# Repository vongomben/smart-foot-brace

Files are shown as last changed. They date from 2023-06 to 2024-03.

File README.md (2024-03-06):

A project managed by [Officine Innesto](https://officine.cc/smart-foot-brace-a-project-with-its-biotecnologie-from-colleretto-giacosa/) in collaboration with students from [ITS Biotecnologie](https://www.its-biotecnologiepiemonte.it/) from Colleretto Giacosa / Torino, Italy. 

# smart-foot-brace
notes over a smart foot brace based on ZNX-01 and IMU, communicating with a Node-RED UI (vers 01. and 0.2) and later using [BLE and P5js](https://github.com/vongomben/smart-foot-brace/tree/main/ble) (vers 0.3)

## Version 0.3 Bluetooth Low Energy Version

Video Demo (https://www.youtube.com/watch?v=2Io1VRFC9aA)

The sole sends data via BLE. 
To visualize this project we used p5js, and its implementation of the BLE library
Here is [the code](https://editor.p5js.org/vongomben/sketches/Wb9gCTJpH)

La suola trasmette tutti i dati attraverso bluetooth. 
Per visualizzare questo progetto abbiamo usato p5js, e la sua implementazione della libreria BLE
Qui il [codice](https://editor.p5js.org/vongomben/sketches/Wb9gCTJpH)

## Version 0.2 ESP32 + ZNX + IMU! + UI in Node-RED

Video Demo (https://www.youtube.com/watch?v=2a6iHeYnoPc)
(sorry this is note yet subtitled)

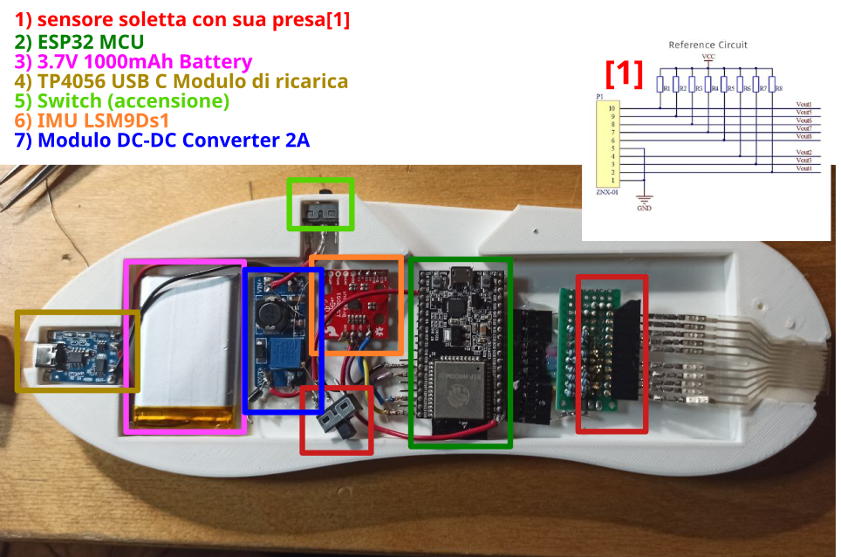
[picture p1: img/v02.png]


|ref|description |label  |Manufacturer|MPN |DPN |link |
|---|---|---|---|---|---|---|
|1  |Sensore Soletta |ZNX-01 |Qiter |Qiter4hr835o19f |B08CXZ6QWM |https://www.amazon.it/intelligente-pressione-Accessorio-tappetino-sensibile/dp/B08CXZ6QWM |
|2  |MCU |ESP32  |AZDelivery  |B071P98VTG |B071P98VTG |https://www.amazon.it/AZDelivery-NodeMCU-Development-Arduino-gratuito/dp/B071P98VTG/ |
|3  | 3.7V 1000mAh Battery |Battery|AKZYTUE |A202106326 |A202106326 |https://www.amazon.it/AKZYTUE-Batteria-ricaricabile-polimeri-connettore/dp/B0983K9BMK/ |
|4  |TP4056 USB C Tipo C Modulo di ricarica (3)|Charger|RED DAMORE  |B0BJQPN3RG |B0BJQPN3RG |https://www.amazon.it/RED-DAMORE-ricarica-batteria-protezione/dp/B0BJQPN3RG/ |
|~5~  |~DC-DC Buck Converter (6)~ |Buck |DUBEUYEW |B0B4SYBGQL |B0B4SYBGQL |https://www.amazon.it/DUBEUYEW-Converter-Modulo-alimentazione-regolabile/dp/B0B4SYBGQL |
|6  |Interruttore a Scorrimento |SWITCH |RUNCCI-YUN  |B09TVDZ8P2 |B09TVDZ8P2 |https://www.amazon.it/RUNCCI-YUN-Interruttore-Scorrimento-Posizione-Elettronici/dp/B09TVDZ8P2/|
|7  |FILAMENT |3D |SUNLU |‎SLUK-TPU-WT-0.5KG|‎SLUK-TPU-WT-0.5KG|https://www.amazon.it/SUNLU-Filament-Dimensional-Accuracy-Printing/dp/B07R6PMXSP |
|8  |IMU LSM9Ds1 |IMU |Sparkfun |SEN-13284 |SEN-13284 |https://www.sparkfun.com/products/retired/13284 |
|9  |MODULO DC-DC BOOST CONVERTER 2 AMPERE |Buck |Pinto |056.044.3838 |056.044.3838 | |

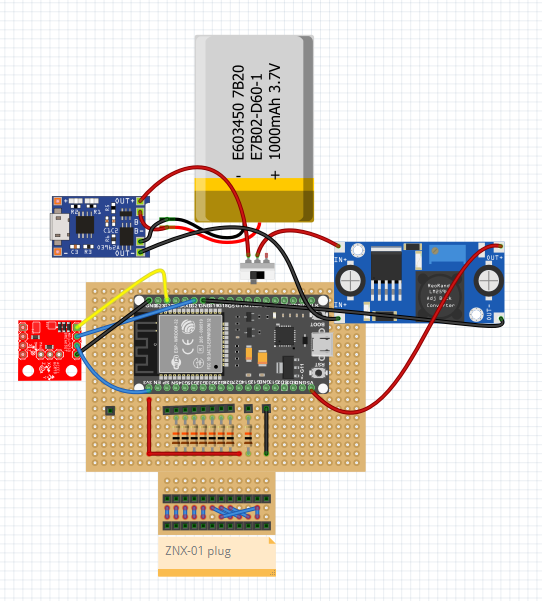
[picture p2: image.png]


Old info about version #1 (Italian only)

## Version 0.1 ESP32 + ZNX + UI in Node-RED

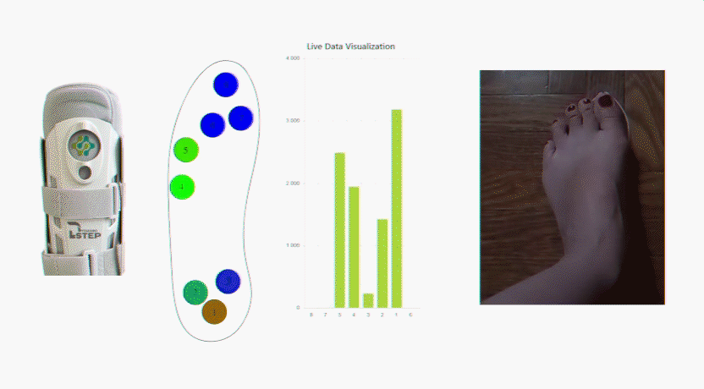
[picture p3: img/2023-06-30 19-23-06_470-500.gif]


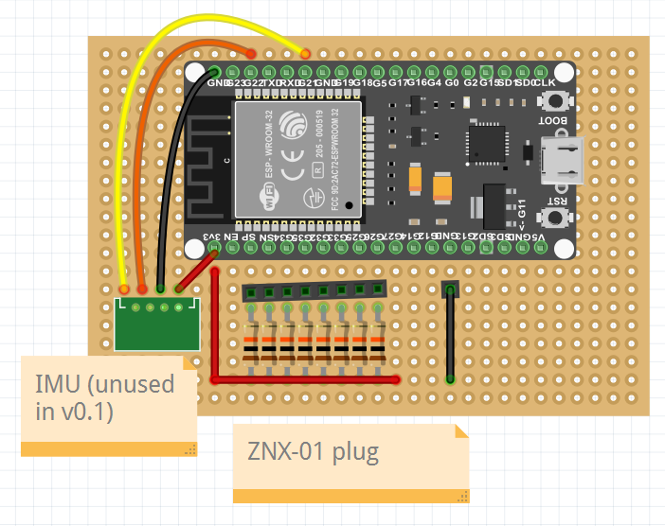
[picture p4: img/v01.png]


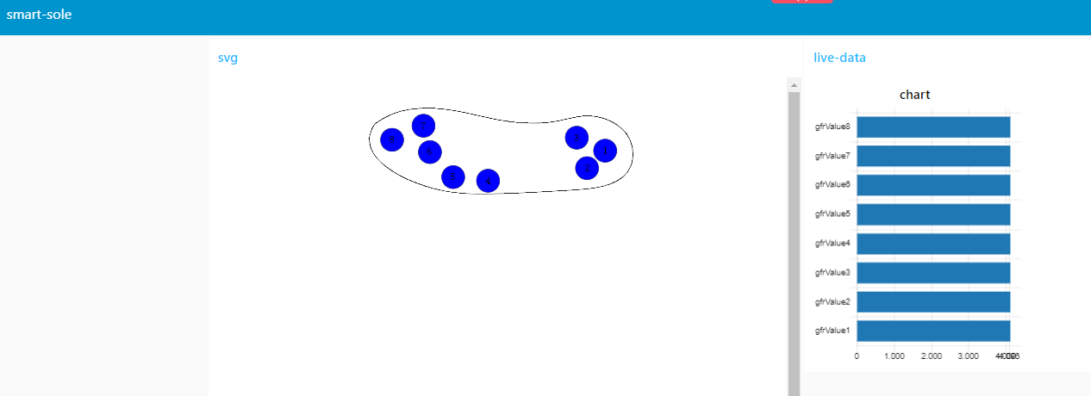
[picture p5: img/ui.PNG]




## Come si usa il prototipo 1?

Per poter visualizzare sul PC i dati della suola smart occorre:

### Lato Arduino (Opzionale)

* installare Arduino
* installare il [core dell'ESP32](https://randomnerdtutorials.com/installing-the-esp32-board-in-arduino-ide-windows-instructions/)

### Lato Node-RED (obbligatorio)

* [installare Node-RED](https://nodered.org/docs/getting-started/windows) sulla propria macchina
* installare il node per la gestione della [porta seriale](https://flows.nodered.org/node/node-red-node-serialport)
* installare il nodo [dashboard](https://flows.nodered.org/node/node-red-dashboard)
* installare il nodo per la gestione degli [svg nella dashboard](https://flows.nodered.org/node/node-red-contrib-ui-svg) 

Una volta fatte queste operazione e importata la prima versione della UI, dovrete correttamente identificare la COM che il vostro PC ha assegnato all'ESP32. Selezionandola dal dropdown del nodo dovreste essere in grado di vedere i dati vairare in tempo reale nella dashaboard.

Al momendo la comunicazione é seriale, i dati vengono inviati in JSON, in questo protocollo:

```
{
    "vers" : 1,
    "gfrValue8" : num,
    "gfrValue7" : num,
    "gfrValue6" : num,
    "gfrValue5" : num,
    "gfrValue4" : num,
    "gfrValue3" : num,
    "gfrValue2" : num,
    "gfrValue1" : num
}
```

# TODO:

* [ ] [Implementare correttamente una IMU](https://github.com/vongomben/smart-foot-brace/issues/1)
* [ ] [Capire che PC usare nell'installazione](https://github.com/vongomben/smart-foot-brace/issues/2)
* [ ] [Passare a Arduino NANO 33 IoT](https://github.com/vongomben/smart-foot-brace/issues/3) (possibilità)
* [ ] [Acquisti](https://github.com/vongomben/smart-foot-brace/issues?q=is%3Aissue+is%3Aopen+label%3Aacquisti)
* [ ] [Definire comportamenti ed usi sbagliati del tutore](https://github.com/vongomben/smart-foot-brace/issues/5)
* [ ] [approvare la colorazione della heatmap](https://github.com/vongomben/smart-foot-brace/issues/6)
* [ ] [prototipare (anche su carta) l'interfaccia che si vuole raggiungere (Con almeno tre livelli di completezza: good better best)](https://github.com/vongomben/smart-foot-brace/issues/9)
* [ ] [Creazione di una BOM](https://github.com/vongomben/smart-foot-brace/issues/7) (meglio su gDrive) che faccia elendo dei pezzi in essere
* [ ] [File 3D del gesso](https://github.com/vongomben/smart-foot-brace/issues/8)

## Various links 

* [ZNX-01 Sensing Mat,Foot Pressure Sensor Insole Sensor Plastic Sensing Mat Thin Film Pressure Sensor Thin Film Intelligent Insole Sensor Foot Pressure Sensor](https://www.amazon.com/ZNX-01-Sensing-Pressure-Plastic-Intelligent/dp/B09PF5TNS8)  
* [Gait Phase Recognition Using Fuzzy Logic Regulation with Multisensor Data Fusion](https://www.hindawi.com/journals/js/2021/8776059/)
* [Foot Pronation Detection Based on Plantar Pressure Measurement](https://www.researchgate.net/publication/346509459_Foot_Pronation_Detection_Based_on_Plantar_Pressure_Measurement)

## Specification

* Item Type	Sensing Mat
* Material	Plastic
* Model	ZNX-01
* Thickness	Approx. 0.45mm / 0.02in
* Single Point Range	Approx. 10 kg / 22 lb
* Response Point Range	Approx. 400 g / 14.1 oz
* Durability	>1 million times
* Initial Resistance	>10MQ (no load)
* Test Voltage	Typical value DC3.3V
* Response Time	<1ms
* Recovery Time	<15ms
* Working Temperature	-20℃~60℃
* Electromagnetic Interference	No generation
* Electrostatic Discharge ESD	Not sensitive

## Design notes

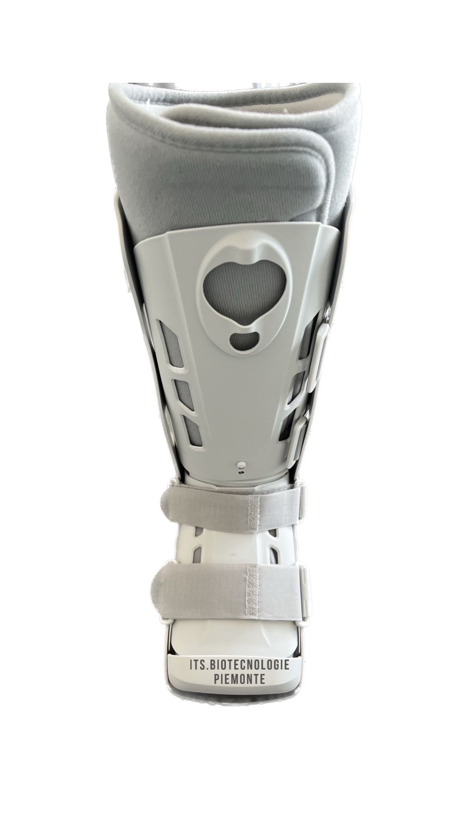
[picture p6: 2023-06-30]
img/data-from-students/back.jpeg

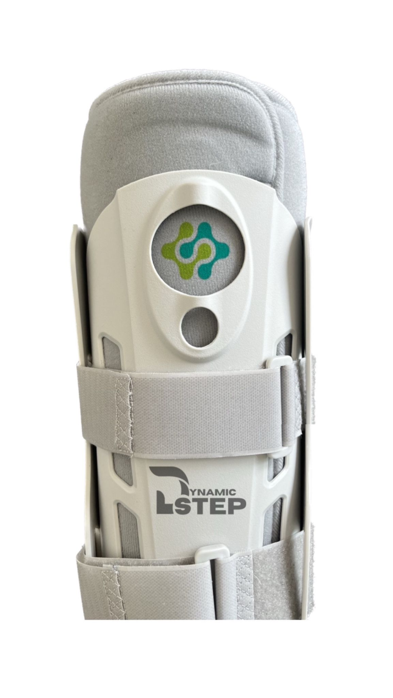
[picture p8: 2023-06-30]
img/front-double-3.png

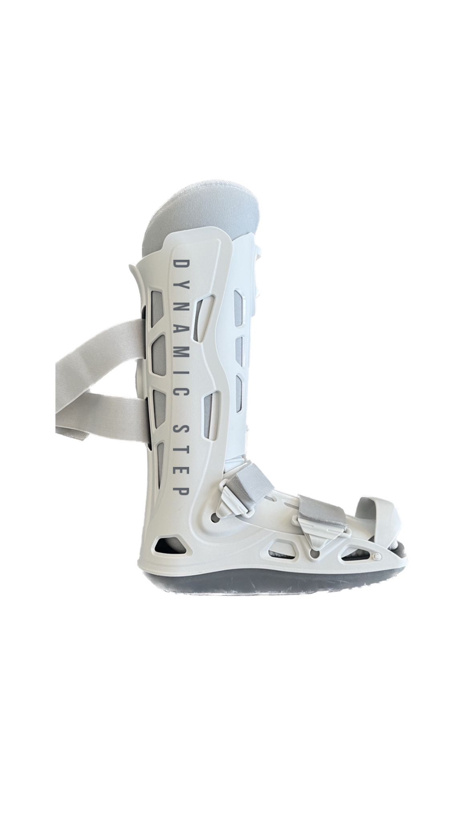
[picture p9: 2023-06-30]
img/data-from-students/lateral.jpeg

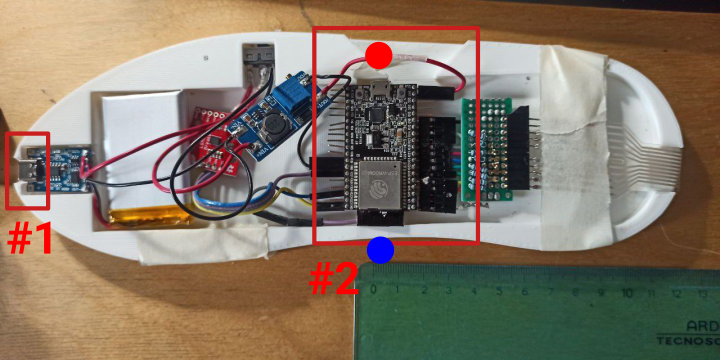
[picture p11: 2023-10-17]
img/review-17-oct/housing.png

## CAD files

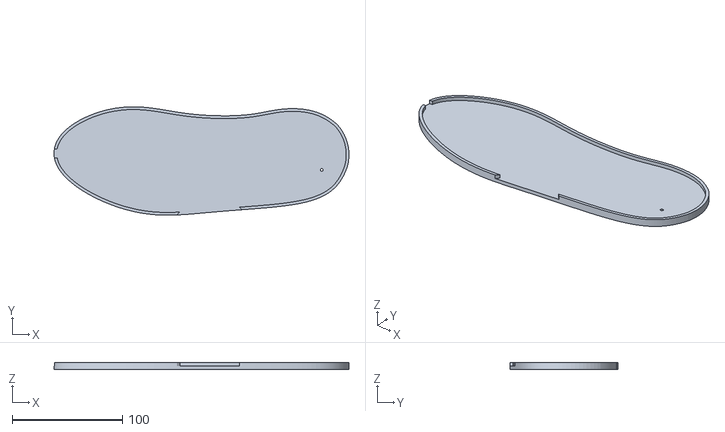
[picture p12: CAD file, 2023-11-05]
3D designs/Coperchio.stl
267.0 x 98.1 x 6.00

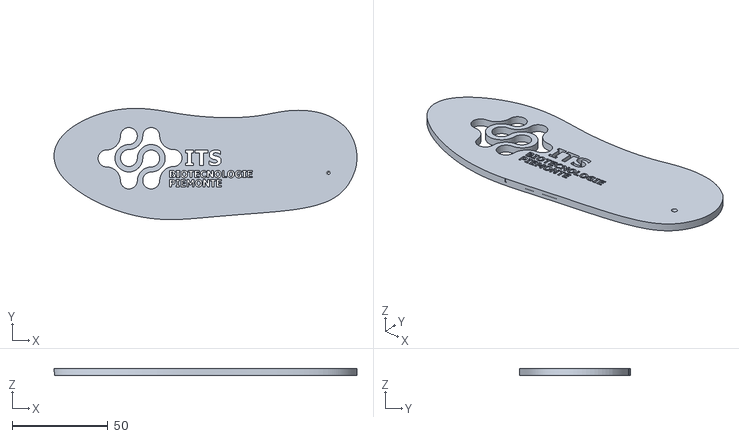
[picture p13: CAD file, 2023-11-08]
img/sole-logo-through.stl
158.0 x 58.0 x 3.54

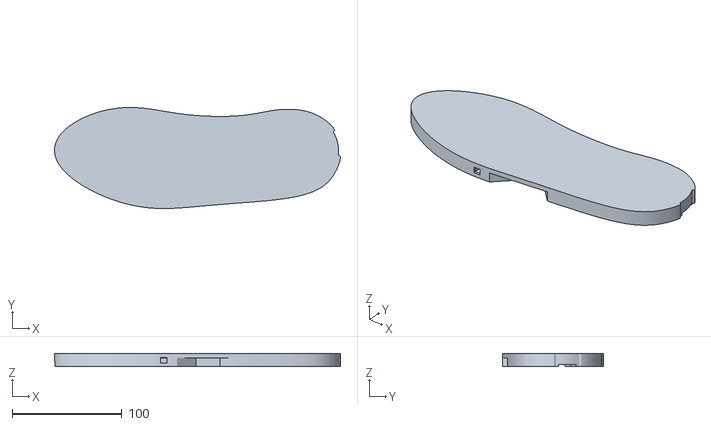
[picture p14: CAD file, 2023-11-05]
3D designs/Soletta componenti.stl
260.7 x 92.1 x 12.0

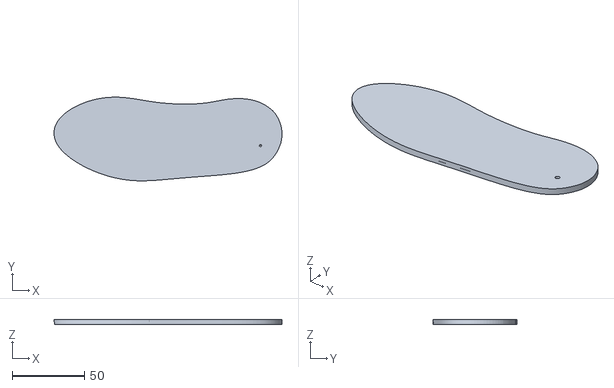
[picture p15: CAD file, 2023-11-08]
img/sole-noLogo.stl
158.0 x 58.0 x 3.54

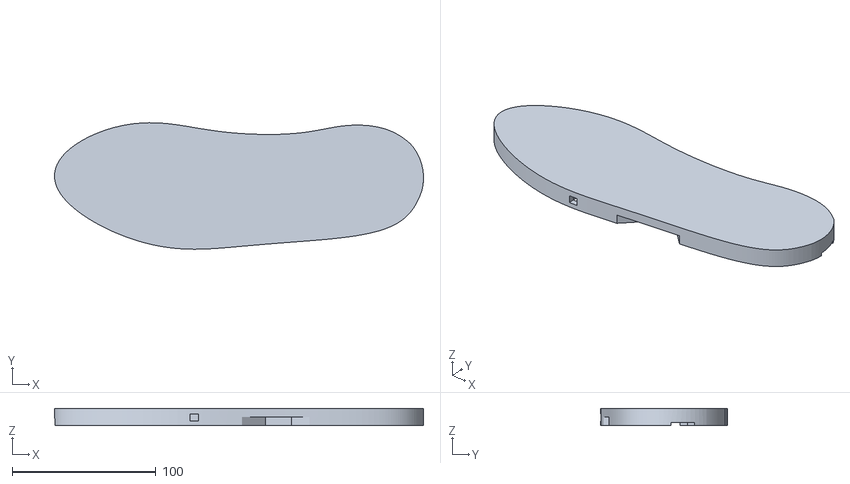
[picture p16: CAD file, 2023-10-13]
3D designs/Smart foot brace v3.stl
257.0 x 88.1 x 12.0

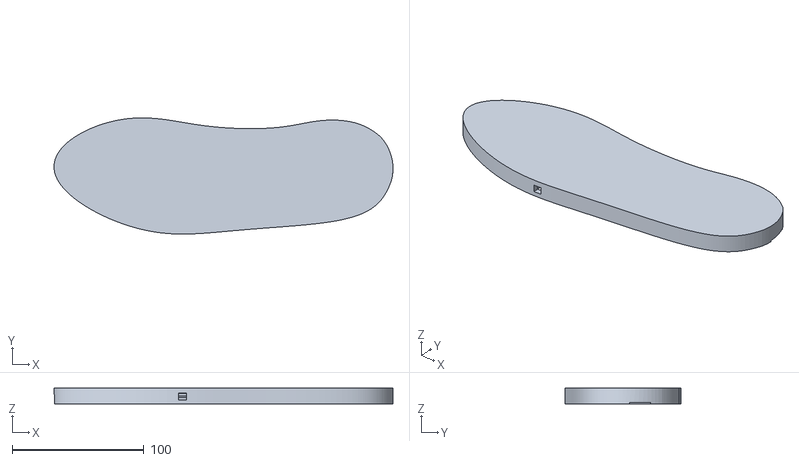
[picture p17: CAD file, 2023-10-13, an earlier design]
3D designs/Smart foot brace v1.stl
257.0 x 88.1 x 12.0

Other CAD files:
img/sole-logoPrint.stl
3D designs/Smart foot brace v1.f3d
3D designs/Smart foot brace v13.f3d
3D designs/Smart foot brace v3.f3d
3D designs/Smart foot brace v9.f3d

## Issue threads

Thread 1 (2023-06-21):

Implementare correttamente una IMU (non inclusa in vers 0.1)

vongomben, 2023-06-21:
Brevi storie tristi di implementazione della IMU nel progetto (ogni punto é un problema)

1) Ho inizialmente provato (con successo) a attaccare, leggere ed inviare una [MPU6050 all'ESP32 via I2C](https://randomnerdtutorials.com/esp32-mpu-6050-accelerometer-gyroscope-arduino/) (come si vede dal diagramma di Fritzing).

Purtroppo dopo un po' (un bel po', un paio di giorni) ho cominciato ad avere [questo errore](https://forum.arduino.cc/t/mpu-6050-returning-zero-values/522038). Non sembrerebbe (almeno nel mio caso) essere un problema di alimentazione (la scheda é a 3v3 e i cablaggi sono stati verificati, ma  il problema si é ripetuto con una certa frequenza.

2) Altro grosso problema: quando la comunicazione era operativa, ho notato grandi rallentamenti nel mio PC (legato a #2) e nella graficizzazione dei dati di IMU in tempo reale, anche se la frequenza di campionamento era relativamente bassa.

3) Ho quindi testato la [9DOF Grove di Seeedstudio](https://wiki.seeedstudio.com/Grove-IMU_9DOF_v2.0/) con l'ESP32, ma sono incappato in [questo errore](https://github.com/espressif/arduino-esp32/issues/508), che richiede più tempo per essere risolto.

4) Ho quindi pensato che per risolvere questo problema e valorizzate la Arduino Nano 33 IoT e la sua IMU a bordo, potevamo passare a quella scheda.
Da un primo test la IMU funziona, ma non quando viene inviato tutto in JSON e seriale. In questo caso il dato viene inviato una sola volta.

Per questi problemi non ho aggiunto la IMU nella prima versione del progetto

Closed 2023-10-20.

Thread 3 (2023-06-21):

Passare a Arduino NANO 33 IoT

vongomben, 2023-06-21:
Potrebbe essere interessante la migrazione del progetto a Arduino Nano 33 IoT, o magari avere due versioni del progetto

marioantonaci, 2023-06-21:
Se l'acquisto è funzionale ad un invio dati via bluetooth o wifi, è necessario acquistare con rapidità

vongomben, 2023-06-22:
Non lo é, tutte le schede che abbiamo lo permettono. L'ITS é in possesso di queste schede

vongomben, 2023-09-08:
Ad oggi vorrei mantenere il deisgn basato su ESP32 per un tema di numero di pin

Source: https://github.com/vongomben/smart-foot-brace/issues/10

Closed 2023-10-20.

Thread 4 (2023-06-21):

Necessità di altre due suole

vongomben, 2023-06-21:
La suola ZNX-01 acquistata é un piede sinistro.
Potrebbe essere necessario comprarne altre due per agevolare la prototipazione

marioantonaci, 2023-06-21:
Ok, rinvierei all'autunno gli acquisti

Closed 2023-11-17.

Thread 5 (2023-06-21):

Definire comportamenti ed usi "corretti" e "sbagliati" del tutore

vongomben, 2023-06-21:
Alla luce delle letture [1] e dei limite tecnici di questo sensore, abbiamo un dato a 12 bit [2] per ogni GRF.

Il dato c'é, ma quali livelli di pressione sono corretti, e quali sbagliati?

### Quale [euristica](https://it.wikipedia.org/wiki/Algoritmo_euristico) dobbiamo implementare per capire se il tutore viene usato non correttamente?

[1]
### Various links

[ZNX-01 Sensing Mat,Foot Pressure Sensor Insole Sensor Plastic Sensing Mat Thin Film Pressure Sensor Thin Film Intelligent Insole Sensor Foot Pressure Sensor](https://www.amazon.com/ZNX-01-Sensing-Pressure-Plastic-Intelligent/dp/B09PF5TNS8)
[Gait Phase Recognition Using Fuzzy Logic Regulation with Multisensor Data Fusion](https://www.hindawi.com/journals/js/2021/8776059/)
[Foot Pronation Detection Based on Plantar Pressure Measurement](https://www.researchgate.net/publication/346509459_Foot_Pronation_Detection_Based_on_Plantar_Pressure_Measurement)

### Specification

Item Type Sensing Mat
Material Plastic
Model ZNX-01
Thickness Approx. 0.45mm / 0.02in
Single Point Range Approx. 10 kg / 22 lb
Response Point Range Approx. 400 g / 14.1 oz
Durability >1 million times
Initial Resistance >10MQ (no load)
Test Voltage Typical value DC3.3V
Response Time <1ms
Recovery Time <15ms
Working Temperature -20℃~60℃
Electromagnetic Interference No generation
Electrostatic Discharge ESD Not sensitive

[2] (Risoluzione dell'ADC di 12 bit: 212 = 4096 livelli di quantizzazione)

marioantonaci, 2023-06-21:
Al momento, per la consegna del 5 luglio non ci sarà bisogno di ragionare su valori limite e soglie. Dobbiamo dimostrare invece che il sensore restituisce valori di pressione, possibilmente graficandoli sul pc

vongomben, 2023-06-22:
Perfetto. E' già così

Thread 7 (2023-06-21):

Creazione BOM

vongomben, 2023-06-21:
Va creata una BOM seguendo queste linee guida
https://github.com/vongomben/ITS-Bio-2023/issues/3

vongomben, 2023-10-10:
[Bom](https://docs.google.com/spreadsheets/d/e/2PACX-1vR7YMZS-MX4lgYpCrwV-KHx-E0jnsvpv04R4XSrfAN4V9t7ghrDI92tuOamuOgdfb9chOnYX6ybkv2q/pubhtml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):

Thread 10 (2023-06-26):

Arduino Nano 33 IoT problems in sending JSON

vongomben, 2023-06-26:
Hi!
Apparently I'm facing an issue which is more interesting and hard than my capabilities.
When using `Arduino_JSON` vers 0.2.0 and `Arduino_LSM6DS3` 1.0.2 I find an interesting issue in dealing with the IMU and the reading of 8 different analog readings.

The code that "silences" the Serial port is this one.

NOTE: if I comment the JSON incapsulation of the analog readings everything keeps on stopping (hence that is not the problem).
Apparently the problem is the 8 analog readings.

Fun Fact: if I add one reading and one JSON incapluation at a time, everything "breaks" when I reach two readings printed (alongside the JSON

Any help from @facchinm

```
#include <Arduino_LSM6DS3.h>
#include <Arduino_JSON.h>

const int grf8 = A1;
const int grf7 = A0;
const int grf6 = A5;
const int grf5 = A6;
const int grf4 = A7;
const int grf3 = A2;
const int grf2 = A3;
const int grf1 = A4;

int gfrValue8 = 0;
int gfrValue7 = 0;
int gfrValue6 = 0;
int gfrValue5 = 0;
int gfrValue4 = 0;
int gfrValue3 = 0;
int gfrValue2 = 0;
int gfrValue1 = 0;

void setup() {
  Serial.begin(115200);
  while (!Serial)
    ;

  if (!IMU.begin()) {
    Serial.println("Failed to initialize IMU!");

    while (1)
      ;
  }

  IMU.accelerationSampleRate();
  IMU.gyroscopeSampleRate();
}

void loop() {
  float x, y, z;
  float Gx, Gy, Gz;

  JSONVar myObject;

  myObject["vers"] = 1;

  gfrValue8 = analogRead(grf8);
  gfrValue7 = analogRead(grf7);
  gfrValue6 = analogRead(grf6);
  gfrValue5 = analogRead(grf5);
  gfrValue4 = analogRead(grf4);
  gfrValue3 = analogRead(grf3);
  gfrValue2 = analogRead(grf2);
  gfrValue1 = analogRead(grf1);

  myObject["gfrValue8"] = gfrValue8;
  myObject["gfrValue7"] = gfrValue7;
  myObject["gfrValue6"] = gfrValue6;
  myObject["gfrValue5"] = gfrValue5;
  myObject["gfrValue4"] = gfrValue4;
  myObject["gfrValue3"] = gfrValue3;
  myObject["gfrValue2"] = gfrValue2;
  myObject["gfrValue1"] = gfrValue1;

  if (IMU.accelerationAvailable()) {
    IMU.readAcceleration(x, y, z);

    myObject["x"] = x;
    myObject["y"] = y;
    myObject["z"] = z;
  }

  if (IMU.gyroscopeAvailable()) {
    IMU.readGyroscope(Gx, Gy, Gz);

    myObject["Gx"] = Gx;
    myObject["Gy"] = Gy;
    myObject["Gz"] = Gz;
  }

  String jsonString = JSON.stringify(myObject);

  Serial.println(jsonString);

  delay(10);
}

```

facchinm, 2023-07-31:
@vongomben the issue is about the "funny" I2C sharing on Nano pinout ( SDA/SCL are shorted with A4/A5). When `analogRead(A4)` is called, the I2C stops being functional  and this locks the sketch when `IMU.accelerationAvailable()` is then called.
If the I2C accelerometer was externally connected, it would be feasible to fix this by using another SERCOM for I2C (https://learn.adafruit.com/using-atsamd21-sercom-to-add-more-spi-i2c-serial-ports/creating-a-new-wire) . Unfortunately, since the connection is internal, there's no chance to use the onboard LSM6DS3 and A4/A5 at the same time :disappointed:

vongomben, 2023-09-08:
Thanks @facchinm

This is a really precious information

vongomben, 2023-10-31:
I could bypass this by using a demux
https://www.youtube.com/watch?v=Dco6jo9xgAo

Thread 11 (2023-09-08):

Problema di interruzione dei dati nella trasmissione dalla soletta sensorizzata tramite cavo USB

Narjise, 2023-09-08:
Abbiamo riscontrato un problema durante l'utilizzo della soletta: quando i cavi USB vengono anche solo leggermente ripiegati su se stessi lungo l'asse Y o Z, si verifica un'interruzione nella trasmissione dei dati.
Sembra che il problema sia concentrato principalmente nella parte iniziale in cui i cavi entrano nel case bianco della soletta. Questa zona sembra essere vulnerabile alle interferenze e alle interruzioni della connessione USB quando i cavi subiscono qualsiasi tipo di flessione o piegatura.
Potrebbe essere necessario considerare una soluzione che migliori la robustezza della connessione USB, ad esempio attraverso l'uso di cavi più resistenti o migliorando la protezione della zona di ingresso dei cavi nel case.
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

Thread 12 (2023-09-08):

Interesting reference design in the "Von Niemann Probe" Project

vongomben, 2023-09-08:
Interesting project for seeing a in-sole design (battery and microcontroller, BT in this case)

Wonderful writing about the parametric design of the sole (in our case is simpler, because we are using a pre-defined measure)

https://teddywarner.org/Projects/VonNiemannProbe/#parametric-shoe-insole

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

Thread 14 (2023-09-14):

Sprint 2

vongomben, 2023-09-14:
Per Maker Faire Rome bisogna realizzare 2 nuovi prototipi, su due suole:
1) una versione "aperta", che permetta di capire il funzionamento del plantare e di toccarlo con mano, vedendo i dati in tempo reale.
2) una versione più definitiva, integrata dentro uno nuovo tutore

Entrambe le versioni sono wireless, quindi:
- sono munite di batteria
- circuito di ricarica
- (optional) sistema di ricarica wireless

Problema: la comunicazione wifi alla fiera di Roma (ma in molte fiere) é complessa. Ho più volte portato questo tipo di dispositivi a Roma per vederli non funzionare. La motivazione principale é che i 13 canali delle reti wifi 2.4 GHz é satura. I dispositivi perdono la connettività. E' da testare come si comporta con un router che esponga i 5 GHz, [ammesso che la scheda che usiamo lo supporti](https://github.com/vongomben/smart-foot-brace/issues/13).

E' probabile che, per ovviare a questo problema, sia necessario creare un server web per ogni dispositivo, usando il firmware ESPHome. Questo permetterà, in caso di non funzionamento della connessione, di cercare la wifi esposta dal dispositivo e sondarne il funzionamento (i.e. i numeri di pressione - non graficizzati - e della IMU)

Il tutto ha anche un aspetto di prototipazione non banale.
Non é chiaro dove si debba mettere l'elettronica, e [non ho una visione di insieme degli ingombri.](https://github.com/vongomben/smart-foot-brace/issues/8), ma penso che la soluzione esteticamente più accattivante é seguire quanto fatto dal progetto della soletta per giocare a scacchi di [Teddy Warner sull'ipotesi di Von Neumann](https://github.com/vongomben/smart-foot-brace/issues/12).

Esteticamente potrebbe essere una cosa di questo tipo, ma ovviamente coperta (ma apribile). Si tratta di capire se i vani e gli spazi siano o meno percepiti dal piede. Insomma, test test test.

E' un lavoro che richiedede almeno una settimana, e l'acquisto di materiali.

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

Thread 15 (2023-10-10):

Sole 3d Design (TPU + PLA)?

vongomben, 2023-10-10:
The [BOM is here](https://docs.google.com/spreadsheets/d/e/2PACX-1vR7YMZS-MX4lgYpCrwV-KHx-E0jnsvpv04R4XSrfAN4V9t7ghrDI92tuOamuOgdfb9chOnYX6ybkv2q/pubhtml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)

As of now, is based on these parts:

|ref|description                               |label  |Manufacturer|MPN               |DPN               |link                                                                                          |
|---|------------------------------------------|-------|------------|------------------|------------------|----------------------------------------------------------------------------------------------|
|1  |Sensore Soletta                           |ZNX-01 |Qiter       |Qiter4hr835o19f   |B08CXZ6QWM        |https://www.amazon.it/intelligente-pressione-Accessorio-tappetino-sensibile/dp/B08CXZ6QWM     |
|2  |MCU                                       |ESP32  |AZDelivery  |B071P98VTG        |B071P98VTG        |https://www.amazon.it/AZDelivery-NodeMCU-Development-Arduino-gratuito/dp/B071P98VTG/          |
|3  | 3.7V 1000mAh Battery                     |Battery|AKZYTUE     |A202106326        |A202106326        |https://www.amazon.it/AKZYTUE-Batteria-ricaricabile-polimeri-connettore/dp/B0983K9BMK/        |
|4  |TP4056 USB C Tipo C Modulo di ricarica (3)|Charger|RED DAMORE  |B0BJQPN3RG        |B0BJQPN3RG        |https://www.amazon.it/RED-DAMORE-ricarica-batteria-protezione/dp/B0BJQPN3RG/                  |
|~5~  |~DC-DC Buck Converter (6)~                  |Buck   |DUBEUYEW    |B0B4SYBGQL        |B0B4SYBGQL        |https://www.amazon.it/DUBEUYEW-Converter-Modulo-alimentazione-regolabile/dp/B0B4SYBGQL        |
|6  |Interruttore a Scorrimento                |SWITCH |RUNCCI-YUN  |B09TVDZ8P2        |B09TVDZ8P2        |https://www.amazon.it/RUNCCI-YUN-Interruttore-Scorrimento-Posizione-Elettronici/dp/B09TVDZ8P2/|
|7  |FILAMENT                                  |3D     |SUNLU       |‎SLUK-TPU-WT-0.5KG|‎SLUK-TPU-WT-0.5KG|https://www.amazon.it/SUNLU-Filament-Dimensional-Accuracy-Printing/dp/B07R6PMXSP              |
|8  |IMU LSM9Ds1                               |IMU    |Sparkfun    |SEN-13284         |SEN-13284         |https://www.sparkfun.com/products/retired/13284                                               |
|9  |MODULO DC-DC BOOST CONVERTER 2 AMPERE     |Buck   |Pinto       |056.044.3838      |056.044.3838      |                                                                                              |

Here is my idea of the fittings (part numer 9 is in the place of 5, which is not used anymore:

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

vongomben, 2023-10-10:
ZNX-01
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

vongomben, 2023-10-13:
Review 13 Ottobre.
grandissimo lavoro di @abenfante
Problemi alla fine.
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

abenfante, 2023-10-13:
Grazie, tutto chiaro, la canaletta del punto B serve che arrivi allo MCU, giusto?

vongomben, 2023-10-13:
La canaletta deve raggiungere la mcu, e la 4 la farei più larga in entrambe le direzioni

vongomben, 2023-10-17:
Review 17 Ottobre:
tutto funge, ma dobbiamo shiftware l'esp32 ancora più a sinistra, permettendogli di stare un poì più verso il basso (mi riferisco all'immagine) in modo da peremettere alla presa della suola di rimanere dreitta entrando sotto, e non leggermente ondulata.

nel punto 1 ho dovuto tagliare qualche millimetro su entrambi i lati, altrimenti la presa USB C non entrava
nel punto  2 shiftando di approx 15mm a sinistra il vano della presa per programmare ESP32. Come dicevo poco più sopra un po' di spazio per l'antenna permetterbbe di abbassare l'ingresso della suola sensoristica.

LAST AND MORE IMPORTANT: mettere tutto allo stesso livello! ci serve la stessa profondità sul modulo ESP32, la stessa della batteria per intenderci.

e ci serve il coperchio (opzionale, perché é sicuramente instruttivo il vedere sotto la suola cosa c'é)

se metto in stampa per domani mattina é tutto pronto

Ottimo lavoro @abenfante

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

vongomben, 2023-10-26:
Il prodotto é solido e resiliente. Abbiamo avuto qualche problema nella comuicazione WIFI, molto meglio investire un po' di tempo per creare una micro app ble.
Unico problema é stato l'ingresso della suola. Ho messo degli elementi fucsia per evidenziarlo. Servirebbe dare più spazio in modo che la superficie trasparente possa aderire facilmente al pavimento e non al bordo
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

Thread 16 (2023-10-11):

BLE visualization via p5 js

vongomben, 2023-10-11:
Alcuni problemi leading to visualization di un json, che sarà composto da:
- heading pitch & roll da IMU
- i dati singoli del sensore di pressione della suola.

al momento non riesco a visualizzarli.

Come codice per testarlo si può usare questo (Senza dove attaccare una IMU, basta una qualunque ESP32)

Io ho fatto qualcosa [qui](https://editor.p5js.org/vongomben/sketches/AQwXVwlqG), ma senza successo (vedo il json arrivare sotto lo "stop", ma viene visto come "undefined" se lo voglio scrivere o usare per  muovere un modello 3D)
IL codice da cui sono partito é quello di @pictux [qui ](https://editor.p5js.org/mpiccin/sketches/N3Qpyd9eO)

In generale sarebbe molto bello avere esempi rectrocompatibili con un solo sketch.js (e non un ble.js separato) che rispettino [questo approccio](https://itpnyu.github.io/p5ble-website/docs/connect-disconnect), ma non si guarda nella bocca del caval donato

Ultima grande domanda che vorei rispondere é: quanto é difficle embeddare questo tipo di visualizzaione dentro una dashabord di node-red?

vongomben, 2023-10-27:
Alcune possibilità per approfondire il tema.
https://developer.chrome.com/articles/bluetooth/

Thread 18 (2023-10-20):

Recap Sprint 2

vongomben, 2023-10-20:
Ieri ho consegnato la versione due del progetto, che consta di:
- housing di tutti i materiali, [con versione in TPU in arrivo](https://github.com/vongomben/smart-foot-brace/issues/15)
- finalizzazione del circuito a batteria (anche se lato alimentazione dobbiamo ancora fare dei test, e probabilmente per fare un lavoro più pulito dovremmo disegnare una schedina custom)
- introduzione della IMU
- graficizzazione via dashboard node-red (piccolo miglioramento rispetto alla prima versione)

Sono state portate avanti tutte le richieste dello [Sprint 2](https://github.com/vongomben/smart-foot-brace/issues/14). Siamo pronti a passare alla versione BLE, però sulla strada abbiamo la problematica di migrazione di tutta [l'interfaccia su P5js](https://github.com/vongomben/smart-foot-brace/issues/16)

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

E' importante ricordare - sopratutto recandosi in un grande evento dove verrà mostrato) che il progetto é ora tra il punto 3 ed il punto 4 della [scala TRL](https://en.wikipedia.org/wiki/Technology_readiness_level). per raggiugnere il punto 5 [1] ci sono alcune problematiche da risolvere (come per esempio capire se il TPU può gestire il peso di una persona,. e miniaturizzare di più il circuito.
Tutto da capire per un ipotetico sprint 3?

[1] Component and/or breadboard validation in relevant environment

vongomben, 2023-10-20:
Al momento la comunicazione avviene via MQTT.
Uno dei problemi che ho riscontrato é che il PC della scuola aveva il Firewall (forse più corretto dire i (numeorsi) firewall attivi.
Ho provato ad aprire la porta 1883, e penso di averlo fatto con successo.
Ho riscontrato comunque grandi problematiche per una comunicazione rapida in una reet locale usando MQTT (nel mio scenario "da laboratorio" tutto funzionava bene).

Ho quindi deciso di usare un [broker online](https://github.com/vongomben/smart-foot-brace/blob/main/basic-01-pub-sub/basic-01-pub-sub.ino#L13) e di aggiornare i dati ogni [5 secondi](https://github.com/vongomben/smart-foot-brace/blob/main/basic-01-pub-sub/basic-01-pub-sub.ino#L226).

Possiamo scendere con i secondi o riprovare a puntare al broker hostato sul pc, ma non sono riuscito a fare test a dovere per motivi di poco tempo (questo sprint é stato tiratissimo, e abbiamo lavorato tutto il fine settimana per poter consegnare giovedì sera)

Sono comunque molto contento dell'esito

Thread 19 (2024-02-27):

Meeting with Davide Gomba

aam19024, 2024-02-27:
Today our Senior Design Project group met with Mr. Davide Gomba to discuss his work with the ZNX-01 sensor and his projects. The meeting was extremely helpful, especially with discussing within the context of a biomedical sensor.
Some key points:
- an IMU should be used to account for the balance of an individual
- Wi-Fi signalling may not be possible due to 100ms delay
- Mr. Gomba already has a Bluetooth signalling protocol set up
- nano EVERY is functional as an processor if no additional components are added
- the array of data most useful to us in under the BLE folder

vongomben, 2024-03-06:
I didnt' use the NANO Every in this project because of the multitples analog pins we need in the project. more [here](https://github.com/vongomben/smart-foot-brace/issues/10)

vongomben, 2024-03-06:
most of the ble related things are [here](https://github.com/vongomben/smart-foot-brace/tree/main/ble)

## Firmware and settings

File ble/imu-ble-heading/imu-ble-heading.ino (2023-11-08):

/*
  ArduinoBLE Potentiometer and Button

  This example creates a BLE peripheral with service that contains a
  characteristic to represents the reading of the potentiometer.

  The circuit:
  - Arduino MKR WiFi 1010 or Arduino Uno WiFi Rev2 board
  - Potentiometer connected to pin A2

  This example code is in the public domain.
*/

#include <ArduinoBLE.h>
#include <Arduino_LSM6DS3.h> // change to Arduino_LSM6DS3.h for Nano 33 IoT or Uno WiFi Rev 2
#include <Wire.h>


const int sensorPin = A2; // set buttonPin to digital pin 4
const int buttonPin = 3; // set buttonPin to digital pin 4

float accelX,            accelY,             accelZ,            // units m/s/s i.e. accelZ if often 9.8 (gravity)
      gyroX,             gyroY,              gyroZ,             // units dps (degrees per second)
      gyroDriftX,        gyroDriftY,         gyroDriftZ,        // units dps
      gyroRoll,          gyroPitch,          gyroYaw,           // units degrees (expect major drift)
      gyroCorrectedRoll, gyroCorrectedPitch, gyroCorrectedYaw,  // units degrees (expect minor drift)
      accRoll,           accPitch,           accYaw,            // units degrees (roll and pitch noisy, yaw not possible)
      complementaryRoll, complementaryPitch, complementaryYaw;  // units degrees (excellent roll, pitch, yaw minor drift)

long lastTime;
long lastInterval;

BLEService sensorService("19B10010-E8F2-537E-4F6C-D104768A1214"); // create service

// create button characteristic and allow remote device to read and write
//BLEIntCharacteristic sensorCharacteristic("19B10012-E8F2-537E-4F6C-D104768A1214", BLERead | BLENotify);
//BLEBoolCharacteristic buttonCharacteristic("19B10013-E8F2-537E-4F6C-D104768A1214", BLERead | BLENotify);
// BLECharacteristic accelerationCharacteristic ("2A5A20B9-0001-4B9C-9C69-4975713E0FF2", BLENotify, sizeof(float) * 3);
//BLEIntCharacteristic accelerationCharacteristic ("2A5A20B9-0001-4B9C-9C69-4975713E0FF2", BLERead | BLENotify);
//BLEIntCharacteristic gyroscopeCharacteristic    ("2A5A20B9-0002-4B9C-9C69-4975713E0FF2", BLERead | BLENotify);
BLECharacteristic RollCharacteristic ("7b193e68-e545-4e5b-9693-c4f9535150ee", BLERead | BLENotify, sizeof(float));
BLECharacteristic PitchCharacteristic ("a057c9f5-148c-4963-9d07-1b098681f04d", BLERead | BLENotify, sizeof(float));
BLECharacteristic YawCharacteristic ("908e0da6-ebd5-465a-b5db-bf398bc98d9f", BLERead | BLENotify, sizeof(float));
//BLECharacteristic PCharacteristic ("19B10013-E8F2-537E-4F6C-D104768A1214", BLERead | BLENotify, sizeof(float) * 3);

void setup() {
  Serial.begin(9600);
  while (!Serial);

  pinMode(sensorPin, INPUT); // use button pin as an input
  pinMode(buttonPin, INPUT); // use button pin as an input

  if (!IMU.begin()) {
    Serial.println("Failed to initialize IMU!");
    while (1);
  }

  calibrateIMU(250, 250);

  lastTime = micros();

  if (!BLE.begin()) {
    Serial.println("Failed to initialize IMU!");
    while (1);
  }

  // begin initialization
  if (!BLE.begin()) {
    Serial.println("starting BLE failed!");

    while (1);
  }

  // set the local name peripheral advertises
  BLE.setLocalName("Sensor Button");

  // set the UUID for the service this peripheral advertises:
  BLE.setAdvertisedService(sensorService);

  // add the characteristics to the service
  //sensorService.addCharacteristic(sensorCharacteristic);
  //sensorService.addCharacteristic(buttonCharacteristic);
  //sensorService.addCharacteristic(accelerationCharacteristic);
  //sensorService.addCharacteristic(gyroscopeCharacteristic);

  sensorService.addCharacteristic(RollCharacteristic);
  sensorService.addCharacteristic(PitchCharacteristic);
  sensorService.addCharacteristic(YawCharacteristic);


  // add the service
  BLE.addService(sensorService);


  //set init value
  //sensorCharacteristic.writeValue(0);
  //buttonCharacteristic.writeValue(0);


  // start advertising
  BLE.advertise();

  Serial.println("Bluetooth device active, waiting for connections...");
}


/*
  the gyro's x,y,z values drift by a steady amount. if we measure this when arduino is still
  we can correct the drift when doing real measurements later
*/
void calibrateIMU(int delayMillis, int calibrationMillis) {

  int calibrationCount = 0;

  delay(delayMillis); // to avoid shakes after pressing reset button

  float sumX, sumY, sumZ;
  int startTime = millis();
  while (millis() < startTime + calibrationMillis) {
    if (readIMU()) {
      // in an ideal world gyroX/Y/Z == 0, anything higher or lower represents drift
      sumX += gyroX;
      sumY += gyroY;
      sumZ += gyroZ;

      calibrationCount++;
    }
  }

  if (calibrationCount == 0) {
    Serial.println("Failed to calibrate");
  }

  gyroDriftX = sumX / calibrationCount;
  gyroDriftY = sumY / calibrationCount;
  gyroDriftZ = sumZ / calibrationCount;

}

/**
   Read accel and gyro data.
   returns true if value is 'new' and false if IMU is returning old cached data
*/
bool readIMU() {
  if (IMU.accelerationAvailable() && IMU.gyroscopeAvailable() ) {
    IMU.readAcceleration(accelX, accelY, accelZ);
    IMU.readGyroscope(gyroX, gyroY, gyroZ);
    return true;
  }
  return false;
}


void loop() {
  // poll for BLE events
  BLE.poll();

  if (readIMU()) {
    long currentTime = micros();
    lastInterval = currentTime - lastTime; // expecting this to be ~104Hz +- 4%
    lastTime = currentTime;

    doCalculations();
    printCalculations();

  }

  /* int sensorValue = analogRead(sensorPin);
    //  Serial.println(sensorValue / 4);
    sensorCharacteristic.writeValue(sensorValue / 4);
    bool buttonValue = digitalRead(buttonPin);
    buttonCharacteristic.writeValue(buttonValue);
*/
RollCharacteristic.writeValue(static_cast<float&>(complementaryRoll));
PitchCharacteristic.writeValue(static_cast<float&>(complementaryPitch));
YawCharacteristic.writeValue(static_cast<float&>(complementaryYaw));
  
/*
  float tempRoll = complementaryRoll;
  float tempPitch = complementaryPitch;
  float tempYaw = complementaryYaw;

  RollCharacteristic.writeValue(tempRoll);
  PitchCharacteristic.writeValue(tempPitch);
  YawCharacteristic.writeValue(tempYaw);

  /*
    RollCharacteristic.writeValue(accRoll);
    PitchCharacteristic.writeValue(accPitch);
    YawCharacteristic.writeValue(accYaw);
  */

}


/**
   I'm expecting, over time, the Arduino_LSM6DS3.h will add functions to do most of this,
   but as of 1.0.0 this was missing.
*/
void doCalculations() {
  accRoll = atan2(accelY, accelZ) * 180 / M_PI;
  accPitch = atan2(-accelX, sqrt(accelY * accelY + accelZ * accelZ)) * 180 / M_PI;

  float lastFrequency = (float) 1000000.0 / lastInterval;
  gyroRoll = gyroRoll + (gyroX / lastFrequency);
  gyroPitch = gyroPitch + (gyroY / lastFrequency);
  gyroYaw = gyroYaw + (gyroZ / lastFrequency);

  gyroCorrectedRoll = gyroCorrectedRoll + ((gyroX - gyroDriftX) / lastFrequency);
  gyroCorrectedPitch = gyroCorrectedPitch + ((gyroY - gyroDriftY) / lastFrequency);
  gyroCorrectedYaw = gyroCorrectedYaw + ((gyroZ - gyroDriftZ) / lastFrequency);

  complementaryRoll = complementaryRoll + ((gyroX - gyroDriftX) / lastFrequency);
  complementaryPitch = complementaryPitch + ((gyroY - gyroDriftY) / lastFrequency);
  complementaryYaw = complementaryYaw + ((gyroZ - gyroDriftZ) / lastFrequency);

  complementaryRoll = 0.98 * complementaryRoll + 0.02 * accRoll;
  complementaryPitch = 0.98 * complementaryPitch + 0.02 * accPitch;
}

/**
   This comma separated format is best 'viewed' using 'serial plotter' or processing.org client (see ./processing/RollPitchYaw3d.pde example)
*/
void printCalculations() {
  /* Serial.print(gyroRoll);
    Serial.print(',');
    Serial.print(gyroPitch);
    Serial.print(',');
    Serial.print(gyroYaw);
    Serial.print(',');
    Serial.print(gyroCorrectedRoll);
    Serial.print(',');
    Serial.print(gyroCorrectedPitch);
    Serial.print(',');
    Serial.print(gyroCorrectedYaw);
    Serial.print(',');
    Serial.print(accRoll);
    Serial.print(',');
    Serial.print(accPitch);
    Serial.print(',');
    Serial.print(accYaw);
    Serial.print(',');
  */
  Serial.print(complementaryRoll);
  Serial.print(',');
  Serial.print(complementaryPitch);
  Serial.print(',');
  Serial.print((int)complementaryYaw);
  Serial.println("");

}

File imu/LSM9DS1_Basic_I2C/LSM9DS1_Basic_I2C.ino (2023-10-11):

/*****************************************************************
  LSM9DS1_Basic_I2C.ino
  SFE_LSM9DS1 Library Simple Example Code - I2C Interface
  Jim Lindblom @ SparkFun Electronics
  Original Creation Date: April 30, 2015
  https://github.com/sparkfun/LSM9DS1_Breakout

  The LSM9DS1 is a versatile 9DOF sensor. It has a built-in
  accelerometer, gyroscope, and magnetometer. Very cool! Plus it
  functions over either SPI or I2C.

  This Arduino sketch is a demo of the simple side of the
  SFE_LSM9DS1 library. It'll demo the following:
  How to create a LSM9DS1 object, using a constructor (global
  variables section).
  How to use the begin() function of the LSM9DS1 class.
  How to read the gyroscope, accelerometer, and magnetometer
  using the readGryo(), readAccel(), readMag() functions and
  the gx, gy, gz, ax, ay, az, mx, my, and mz variables.
  How to calculate actual acceleration, rotation speed,
  magnetic field strength using the calcAccel(), calcGyro()
  and calcMag() functions.
  How to use the data from the LSM9DS1 to calculate
  orientation and heading.

  Hardware setup: This library supports communicating with the
  LSM9DS1 over either I2C or SPI. This example demonstrates how
  to use I2C. The pin-out is as follows:
	LSM9DS1 --------- Arduino
	 SCL ---------- SCL (A5 on older 'Duinos')
	 SDA ---------- SDA (A4 on older 'Duinos')
	 VDD ------------- 3.3V
	 GND ------------- GND
  (CSG, CSXM, SDOG, and SDOXM should all be pulled high.
  Jumpers on the breakout board will do this for you.)

  The LSM9DS1 has a maximum voltage of 3.6V. Make sure you power it
  off the 3.3V rail! I2C pins are open-drain, so you'll be
  (mostly) safe connecting the LSM9DS1's SCL and SDA pins
  directly to the Arduino.

  Development environment specifics:
	IDE: Arduino 1.6.3
	Hardware Platform: SparkFun Redboard
	LSM9DS1 Breakout Version: 1.0

  This code is beerware. If you see me (or any other SparkFun
  employee) at the local, and you've found our code helpful,
  please buy us a round!

  Distributed as-is; no warranty is given.
*****************************************************************/
// The SFE_LSM9DS1 library requires both Wire and SPI be
// included BEFORE including the 9DS1 library.
#include <Wire.h>
#include <SPI.h>
#include <SparkFunLSM9DS1.h>

//////////////////////////
// LSM9DS1 Library Init //
//////////////////////////
// Use the LSM9DS1 class to create an object. [imu] can be
// named anything, we'll refer to that throught the sketch.
LSM9DS1 imu;

///////////////////////
// Example I2C Setup //
///////////////////////
// SDO_XM and SDO_G are both pulled high, so our addresses are:
// #define LSM9DS1_M	0x1E // Would be 0x1C if SDO_M is LOW
// #define LSM9DS1_AG	0x6B // Would be 0x6A if SDO_AG is LOW

////////////////////////////
// Sketch Output Settings //
////////////////////////////
#define PRINT_CALCULATED
//#define PRINT_RAW
#define PRINT_SPEED 250              // 250 ms between prints
static unsigned long lastPrint = 0;  // Keep track of print time

// Earth's magnetic field varies by location. Add or subtract
// a declination to get a more accurate heading. Calculate
// your's here:
// http://www.ngdc.noaa.gov/geomag-web/#declination
#define DECLINATION 3.11  // Declination (degrees) in Turin, IT.


// BLE Stuff
#include "BLESerial.h"
BLESerial bleSerial;


//Function definitions
void printGyro();
void printAccel();
void printMag();
void printAttitude(float ax, float ay, float az, float mx, float my, float mz);

void setup() {
  Serial.begin(115200);
  bleSerial.begin("BLE-UART");
  Wire.begin();

  if (imu.begin() == false)  // with no arguments, this uses default addresses (AG:0x6B, M:0x1E) and i2c port (Wire).
  {
    Serial.println("Failed to communicate with LSM9DS1.");
    Serial.println("Double-check wiring.");
    Serial.println("Default settings in this sketch will "
                   "work for an out of the box LSM9DS1 "
                   "Breakout, but may need to be modified "
                   "if the board jumpers are.");
    while (1)
      ;
  }
}

void loop() {
  // Update the sensor values whenever new data is available
  if (imu.gyroAvailable()) {
    // To read from the gyroscope,  first call the
    // readGyro() function. When it exits, it'll update the
    // gx, gy, and gz variables with the most current data.
    imu.readGyro();
  }
  if (imu.accelAvailable()) {
    // To read from the accelerometer, first call the
    // readAccel() function. When it exits, it'll update the
    // ax, ay, and az variables with the most current data.
    imu.readAccel();
  }
  if (imu.magAvailable()) {
    // To read from the magnetometer, first call the
    // readMag() function. When it exits, it'll update the
    // mx, my, and mz variables with the most current data.
    imu.readMag();
  }
  if (bleSerial.connected()) {
    //Send the analog value


    //Serial.println();
    printGyro();
    printAccel();
    printMag();

    bleSerial.println(imu.ax);
    // bleSerial.println(imu.ay);
    // bleSerial.println(imu.az);
    // bleSerial.println(imu.my);
    // bleSerial.println(imu.mx);
    // bleSerial.println(imu.mz);
    Serial.println();
    //Wait for 0.1 second
    delay(100);
  }
  // if ((lastPrint + PRINT_SPEED) < millis()) {
  //   printGyro();   // Print "G: gx, gy, gz"
  //   printAccel();  // Print "A: ax, ay, az"
  //   printMag();    // Print "M: mx, my, mz"
  //   // Print the heading and orientation for fun!
  //   // Call print attitude. The LSM9DS1's mag x and y
  //   // axes are opposite to the accelerometer, so my, mx are
  //   // substituted for each other.
  //   printAttitude(imu.ax, imu.ay, imu.az,
  //                 -imu.my, -imu.mx, imu.mz);
  //   Serial.println();

  //   lastPrint = millis();  // Update lastPrint time
  // }
}

void printGyro() {
  // Now we can use the gx, gy, and gz variables as we please.
  // Either print them as raw ADC values, or calculated in DPS.
  Serial.print("G: ");
#ifdef PRINT_CALCULATED
  // If you want to print calculated values, you can use the
  // calcGyro helper function to convert a raw ADC value to
  // DPS. Give the function the value that you want to convert.
  Serial.print(imu.calcGyro(imu.gx), 2);
  Serial.print(", ");
  Serial.print(imu.calcGyro(imu.gy), 2);
  Serial.print(", ");
  Serial.print(imu.calcGyro(imu.gz), 2);
  Serial.println(" deg/s");
#elif defined PRINT_RAW
  Serial.print(imu.gx);
  Serial.print(", ");
  Serial.print(imu.gy);
  Serial.print(", ");
  Serial.println(imu.gz);
#endif
}
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

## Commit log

2023-10-13 Aggiunti design 3D
    [Smart foot brace v1.f3d, Smart foot brace v1.stl]
2023-10-13 3D v3
    [Smart foot brace v3.f3d, Smart foot brace v3.stl]
2023-10-17 Ultimi modelli caricati
    [Coperchio.stl, Smart foot brace v9.f3d, Soletta componenti.stl]
2023-10-31 Modificato coperchio e allargato spazio per il connettore della soletta
    [Coperchio.stl, Smart foot brace v13.f3d, Soletta componenti.stl]
